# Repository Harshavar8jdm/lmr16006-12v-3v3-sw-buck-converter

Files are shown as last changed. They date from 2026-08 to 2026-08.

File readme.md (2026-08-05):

readme_content = """# Ultra-Compact 12V to 3.3V Buck Converter Module (LMR16006)







An ultra-compact, high-efficiency step-down (buck) DC-DC converter breakout board designed using Texas Instruments' **LMR16006XDDCR** synchronous buck regulator. This board steps down a nominal 12V DC input (supports up to 60V) to a regulated 3.3V DC output, making it ideal for powering 3.3V microcontrollers (ESP32, STM32, RP2040) and sensors in space-constrained embedded systems and automotive projects.

---

## 📷 Board Preview

| Top View (3D Render) | Bottom View (3D Render) |
| :---: | :---: |
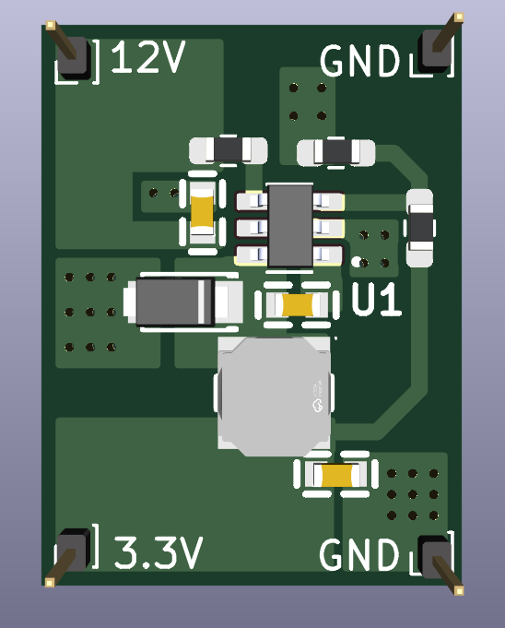
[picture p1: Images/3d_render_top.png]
3D Top View
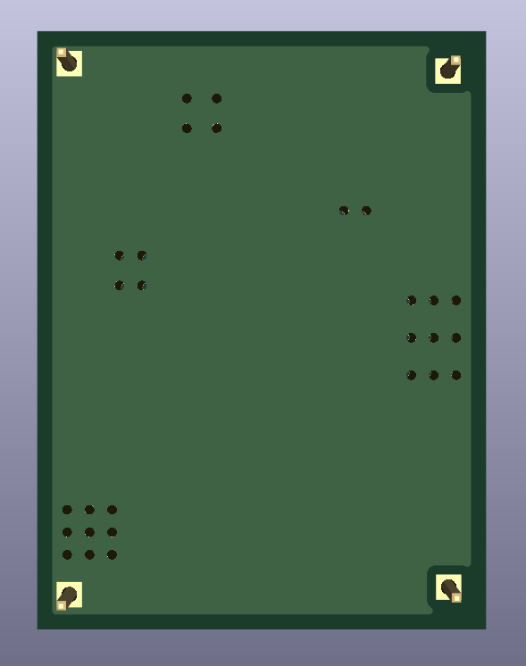
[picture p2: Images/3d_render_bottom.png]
3D Bottom View
|  |  |

---

## ✨ Key Features

- **Ultra-Compact Form Factor:** Tiny **20 mm x 15 mm** footprint with standard 2.54 mm (100 mil) header pins for breadboard integration or carrier board mounting.
- **Wide Input Voltage Range:** Supports $4.2\text{V}$ to $60\text{V}$ input range (configured and tested for 12V step-down).
- **High Efficiency & High Frequency:** $700\text{kHz}$ switching frequency allows the use of small surface-mount inductors and capacitors.
- **Optimized High-Current Loop:** Minimal $di/dt$ switching loop area to suppress high-frequency ringing and electromagnetic interference (EMI).
- **Thermal & Grounding Integrity:** Multi-via stitch arrays on high-power thermal pads (Schottky diode anode and IC GND) to ensure efficient heat dissipation into the bottom ground plane.
- **Truncated SW Polygon:** Reduced copper switching node ($SW$) area to prevent parasitic capacitive radiation.

---

## 📐 Circuit Schematic & Calculations

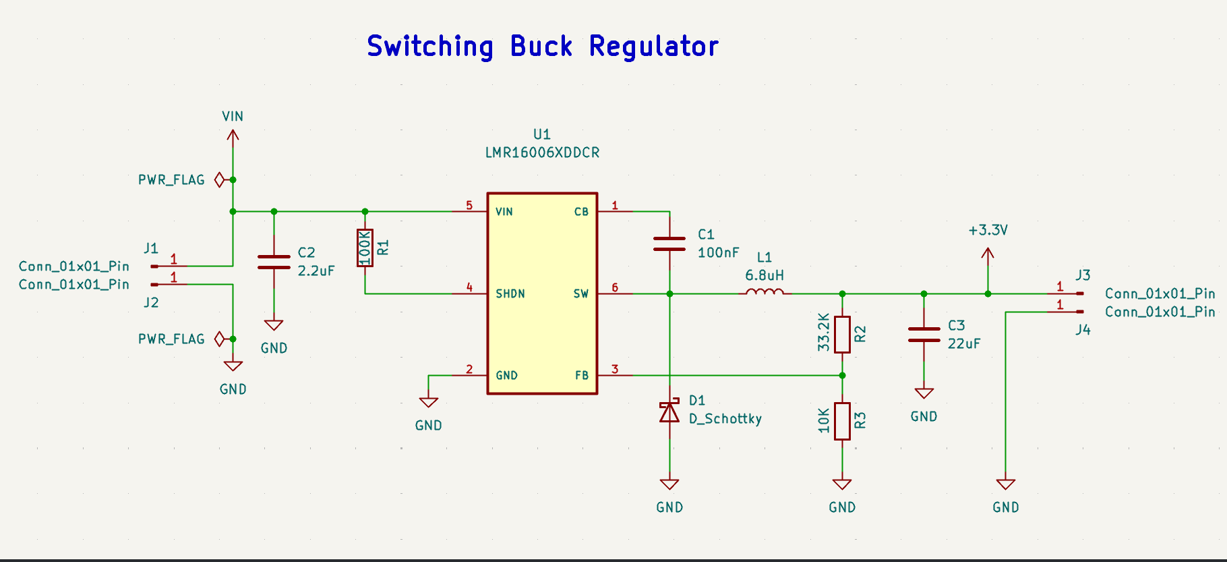
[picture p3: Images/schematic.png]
Schematic


### 1. Output Voltage Selection
The output voltage is configured using a precision feedback resistor divider ($R_2$ and $R_3$) connected to the $FB$ pin ($V_{FB} = 0.765\text{V}$):

$$V_{OUT} = V_{FB} \times \\left(1 + \\frac{R_2}{R_3}\\right)$$

Using standard 1% tolerance resistors:
- $R_2 = 33.2\\text{ k}\\Omega$
- $R_3 = 10.0\\text{ k}\\Omega$

$$V_{OUT} = 0.765\\text{V} \\times \\left(1 + \\frac{33.2\\text{ k}\\Omega}{10.0\\text{ k}\\Omega}\\right) = 0.765\\text{V} \\times 4.32 = \\mathbf{3.305\\text{V}}$$

### 2. Inductor & Switching Selection
- **Inductor ($L_1$):** $6.8\\mu\\text{H}$ power inductor rated for target load current and peak switching ripple.
- **Bootstrap Capacitor ($C_1$):** $100\\text{nF}$ ceramic capacitor driving the internal high-side MOSFET gate driver.
- **Shutdown / Enable ($R_1$):** $100\\text{k}\\Omega$ pull-up resistor tying $SHDN$ to $VIN$ for automatic power-on operation.

---

## 🖼️ PCB Layout & Stackup

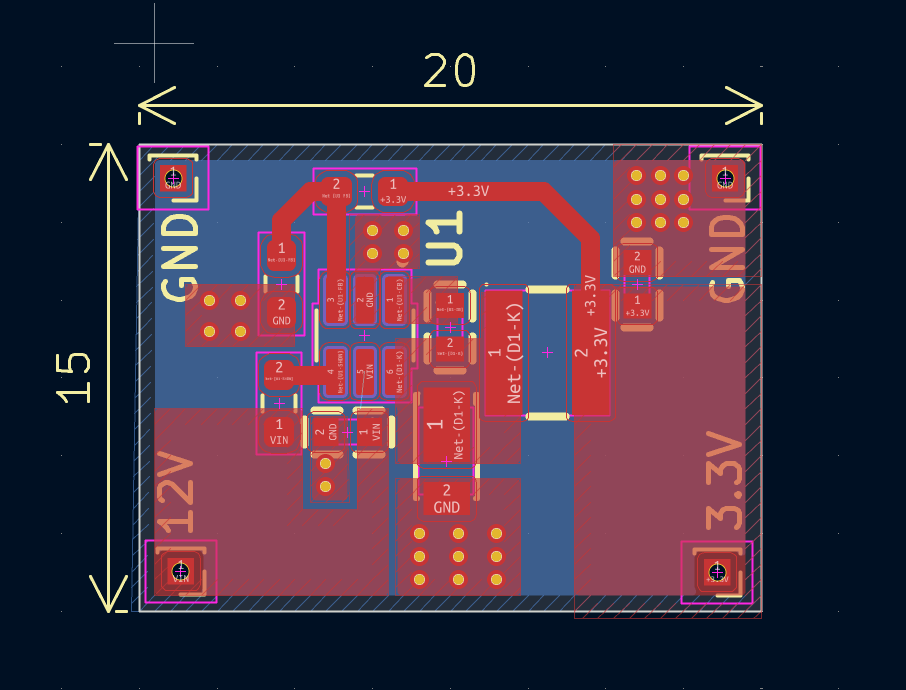
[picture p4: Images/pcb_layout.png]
PCB Layout


### Layout Highlights:
1. **Compact Power Loop:** $C_2$ ($C_{IN}$), $U_1$ ($VIN/SW$), and $D_1$ are placed immediately adjacent to each other to minimize high-frequency AC loop area.
2. **EMI Mitigation:** The SW node copper pour (`Net-(D1-K)`) is tightly constrained to component pads to eliminate unshielded antenna radiation.
3. **Thermal Vias:** A $3\\times 3$ via matrix under the $D_1$ ground pad along with ground stitching around $U_1$ effectively passes heat to the full bottom ground plane layer.
4. **Isolated Feedback Path:** The high-impedance feedback net ($FB$) is routed away from the noisy switching node and inductor body.

---

## 🛒 Bill of Materials (BOM)

| Designator | Quantity | Value / Part Number | Footprint | Description |
| :--- | :---: | :--- | :--- | :--- |
| **U1** | 1 | LMR16006XDDCR | SOT-23-6 (DDC) | 0.6A, 60V, 700kHz Step-Down Regulator |
| **L1** | 1 | 6.8 µH | 4040 / Shielded | Power Inductor |
| **D1** | 1 | Schottky Diode (e.g., B140/SS14) | SMA / SMB | Free-wheeling Catch Diode |
| **C1** | 1 | 100 nF, 50V | 0603 | Bootstrap Capacitor (X7R) |
| **C2** | 1 | 2.2 µF – 10 µF, 50V | 0805 / 1206 | Input Filter Capacitor (X7R) |
| **C3** | 1 | 22 µF, 10V | 0805 | Output Filter Capacitor (X7R) |
| **R1** | 1 | 100 kΩ | 0603 | Shutdown Pull-up Resistor |
| **R2** | 1 | 33.2 kΩ (1%) | 0603 | Feedback Upper Resistor |
| **R3** | 1 | 10.0 kΩ (1%) | 0603 | Feedback Lower Resistor |
| **J1 – J4** | 4 | 1x1 Pin Header | 2.54 mm pitch | Board Power Contacts (12V, GND, 3.3V, GND) |

---

## 🏭 Fabrication Parameters

- **Board Dimensions:** $20\\text{ mm} \\times 15\\text{ mm}$
- **Layer Count:** 2 Layers
- **PCB Thickness:** 1.6 mm
- **Copper Weight:** 1 oz (35 µm)
- **Minimum Trace / Clearance:** 0.25 mm / 0.2 mm
- **Solder Mask Color:** Green (or preferred)
- **Silkscreen:** White

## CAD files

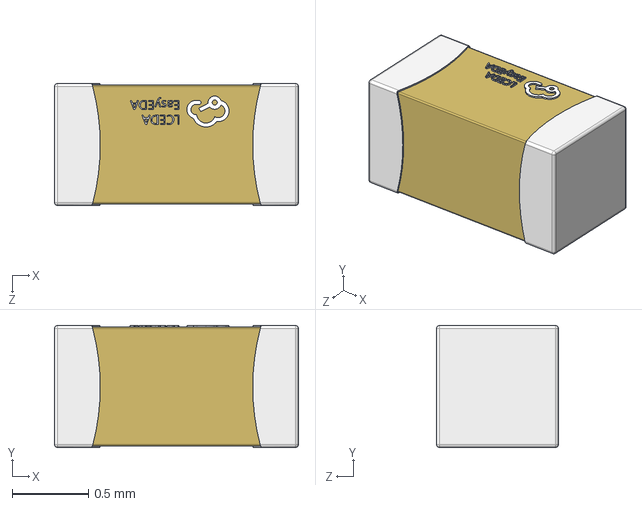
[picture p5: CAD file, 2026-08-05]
ext-libs/Capacitor-100nF/C0603_VJ0603Y104JXQCW1BC_C3834925.step
1.60 x 0.8 x 0.8 mm

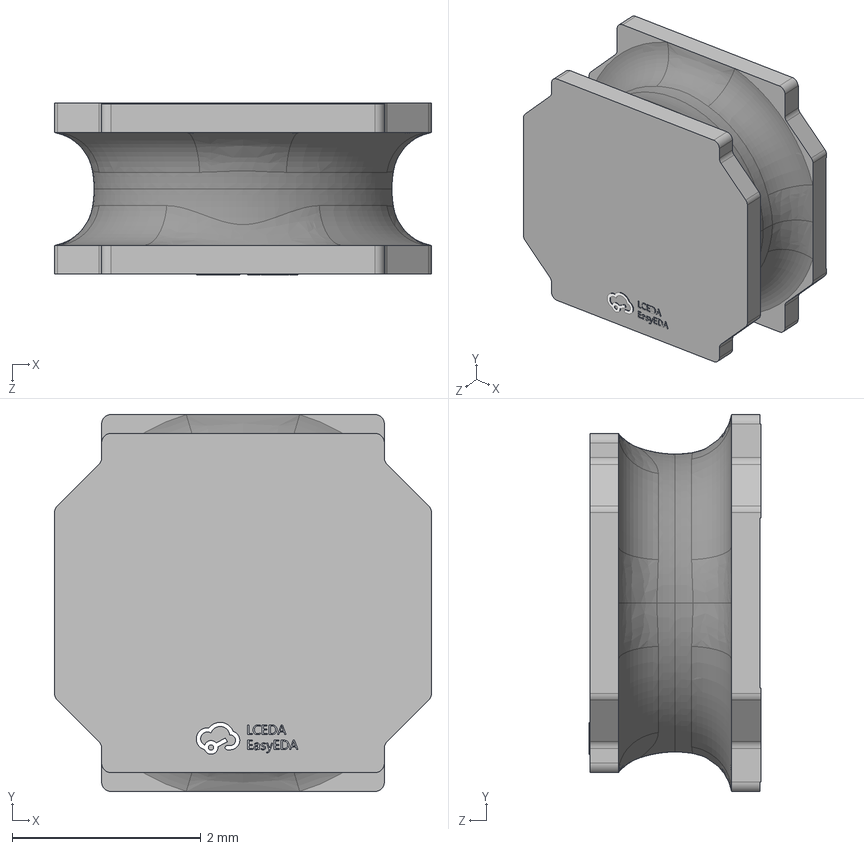
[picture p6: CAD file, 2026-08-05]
ext-libs/Inductor-6.8uH/IND-SMD_L4_0-W4_0_NRS4018T_NRS4018T6R8MDGJ_C222881.step
4.00 x 4.00 x 1.82 mm

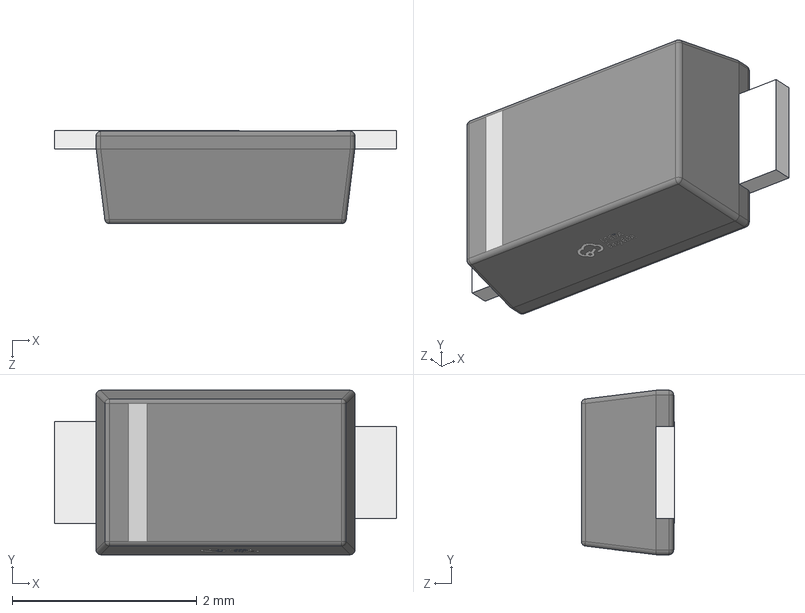
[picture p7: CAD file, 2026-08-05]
ext-libs/Schottky/POWERDI-123_L2_8-W1_8-LS3_7-RD-1_SS14FP_C894423.step
3.70 x 1.78 x 1.01 mm

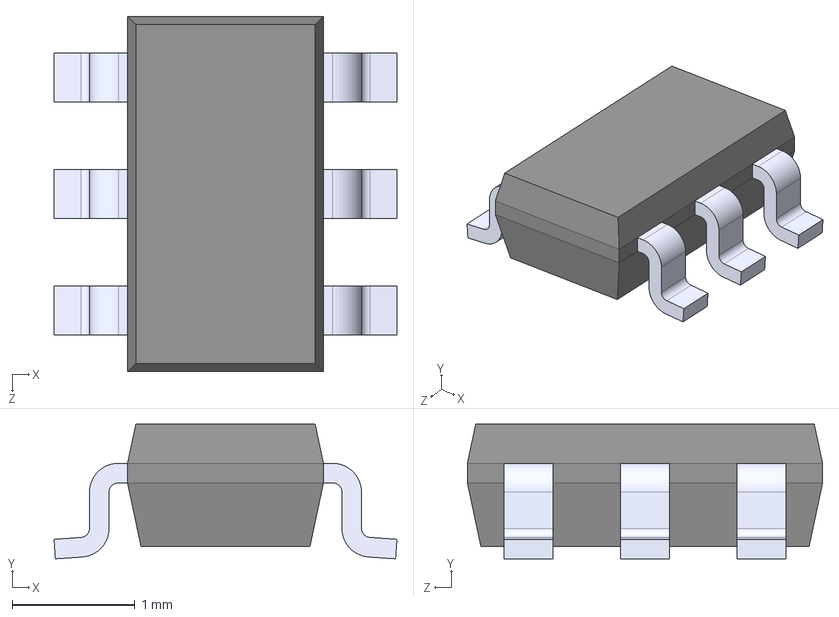
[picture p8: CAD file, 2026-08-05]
ext-libs/LMR16006XDDCR.STEP
2.80 x 1.10 x 2.90 mm

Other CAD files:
ext-libs/Capacitor-100nF/C0603_VJ0603Y104JXQCW1BC_C3834925.obj
ext-libs/Capacitor-2.2uF/C0603_CL10A225KL8NNNC_C307463.obj
ext-libs/Capacitor-22uF/C0603_TCC0603X5R226K100CT_C53032012.obj
ext-libs/Inductor-6.8uH/IND-SMD_L4_0-W4_0_NRS4018T_NRS4018T6R8MDGJ_C222881.obj
ext-libs/Schottky/POWERDI-123_L2_8-W1_8-LS3_7-RD-1_SS14FP_C894423.obj

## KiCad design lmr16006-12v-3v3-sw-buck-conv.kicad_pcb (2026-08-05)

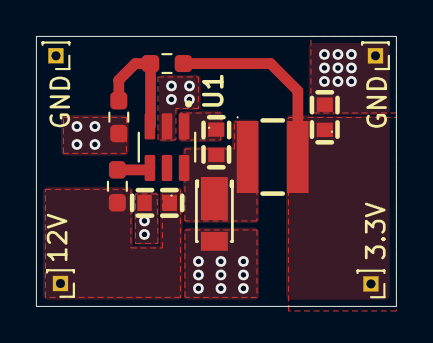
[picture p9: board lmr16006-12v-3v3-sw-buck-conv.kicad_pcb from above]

Board: 2 copper layers, 20.0 x 15.0 mm, 13 parts (0 on the bottom side), 7 nets.

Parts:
3.3V, 12V: Conn_01x01_Pin; PinHeader_1x01_P1.00mm_Vertical
C1: 100nF; C0603_VJ0603Y104JXQCW1BC_C3834925
C2: 2.2uF; C0603_CL10A225KL8NNNC_C307463
C3: 22uF; C0603_TCC0603X5R226K100CT_C53032012
D1: D_Schottky; POWERDI-123_L2_8-W1_8-LS3_7-RD-1_SS14FP_C894423
GND: Conn_01x01_Pin; PinHeader_1x01_P1.00mm_Vertical
GND#2: Conn_01x01_Pin; PinHeader_1x01_P1.00mm_Vertical
L1: 6.8uH; IND-SMD_L4_0-W4_0_NRS4018T_NRS4018T6R8MDGJ_C222881
R1: 100K; R_0603_1608Metric_Pad0.98x0.95mm_HandSolder
R2: 33.2K; R_0603_1608Metric_Pad0.98x0.95mm_HandSolder
R3: 10K; R_0603_1608Metric_Pad0.98x0.95mm_HandSolder
U1: LMR16006XDDCR; SOT95P280X110-6N

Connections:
+3.3V: 3.3V.1 (Pin_1_1), C3.1, L1.2, R2.1
GND: C2.2, C3.2, D1.2 (A), GND.1 (Pin_1_1), GND#2.1 (Pin_1_1), R3.2, U1.2 (GND)
unnamed: C1.2, D1.1 (K), L1.1, U1.6 (SW)
unnamed: C1.1, U1.1 (CB)
unnamed: R2.2, R3.1, U1.3 (FB)
unnamed: R1.2, U1.4 (SHDN)
VIN: 12V.1 (Pin_1_1), C2.1, R1.1, U1.5 (VIN)

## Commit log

2026-08-05 Schematic and PCB Layout
    [C0603_CL10A225KL8NNNC_C307463.obj, C0603_CL10A225KL8NNNC_C307463.step, C0603_TCC0603X5R226K100CT_C53032012.obj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]
2026-08-05 Updated Visuals
    [lmr16006-12v-3v3-sw-buck-conv.kicad_pcb]
2026-08-05 Printed Gerbers
    [lmr16006-12v-3v3-sw-buck-conv-B_Cu.gbr, lmr16006-12v-3v3-sw-buck-conv-B_Mask.gbr, lmr16006-12v-3v3-sw-buck-conv-B_Paste.gbr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]
2026-08-05 Updated Layout with Additional GND Vias
    [lmr16006-12v-3v3-sw-buck-conv.kicad_pcb]
2026-08-05 Updated Layout, Trimmed Excess Copper Pour
    [lmr16006-12v-3v3-sw-buck-conv.kicad_pcb]

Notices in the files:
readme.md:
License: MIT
